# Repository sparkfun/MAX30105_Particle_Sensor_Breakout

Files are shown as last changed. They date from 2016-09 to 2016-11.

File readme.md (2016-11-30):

MAX30105 Particle and Pulse Ox Sensor Breakout
=======

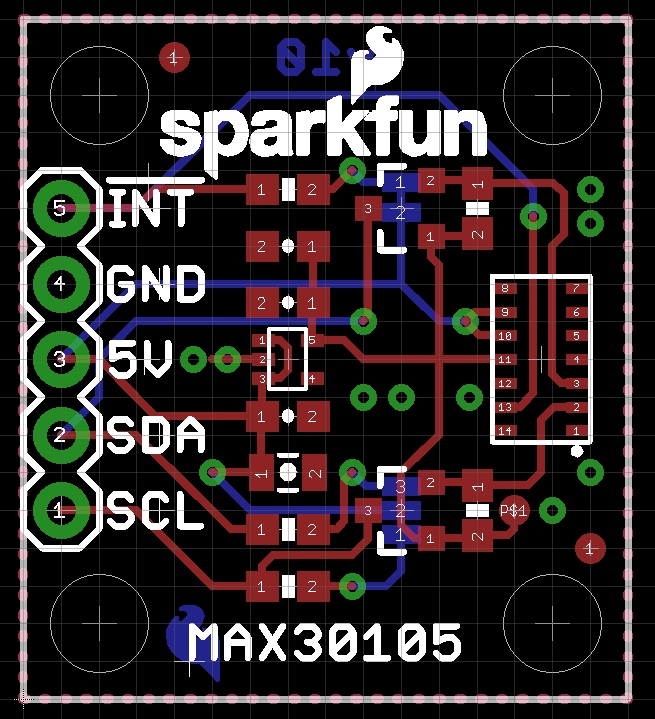
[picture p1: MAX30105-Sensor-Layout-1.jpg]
MAX30105 Breakout Board


A breakout board for the MAX30105 Particle Sensor. This sensor uses three LEDs (Red, Green, IR) to shine different wavelengths of light at any particle in front of the photo detector. Based on the reflection the sensor outputs readings. 

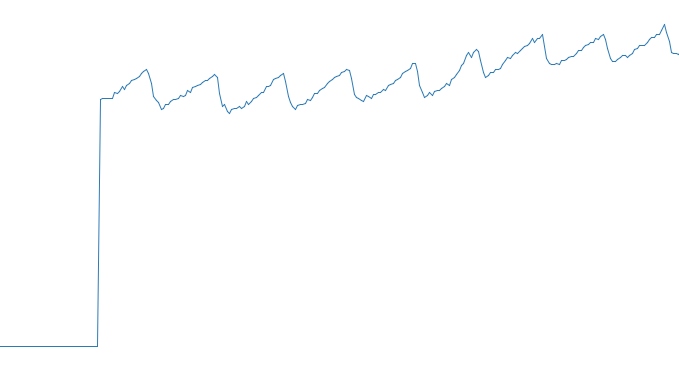
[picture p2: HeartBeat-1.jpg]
Pulse Graph


That's my heart beat!

Sensor is capable of detecting pulses but only limited algorithms are provided. It is up to the user to create the algorithms to detect different particles and/or SPO2 and/or do Pulse Detection.

Board requires 3.3V to operate the IR and Red LEDs. 3.5V is recommended to operate the green LED. It has onboard voltage regulation and BSS138 MOSFETs to convert from larger logic voltages (5V) down to the needed 1.8V.

License Information
-------------------

The hardware is released under [Creative Commons Share-alike 4.0](http://creativecommons.org/licenses/by-sa/4.0/).  
The firmware is released under the [Beerware license](http://en.wikipedia.org/wiki/Beerware).

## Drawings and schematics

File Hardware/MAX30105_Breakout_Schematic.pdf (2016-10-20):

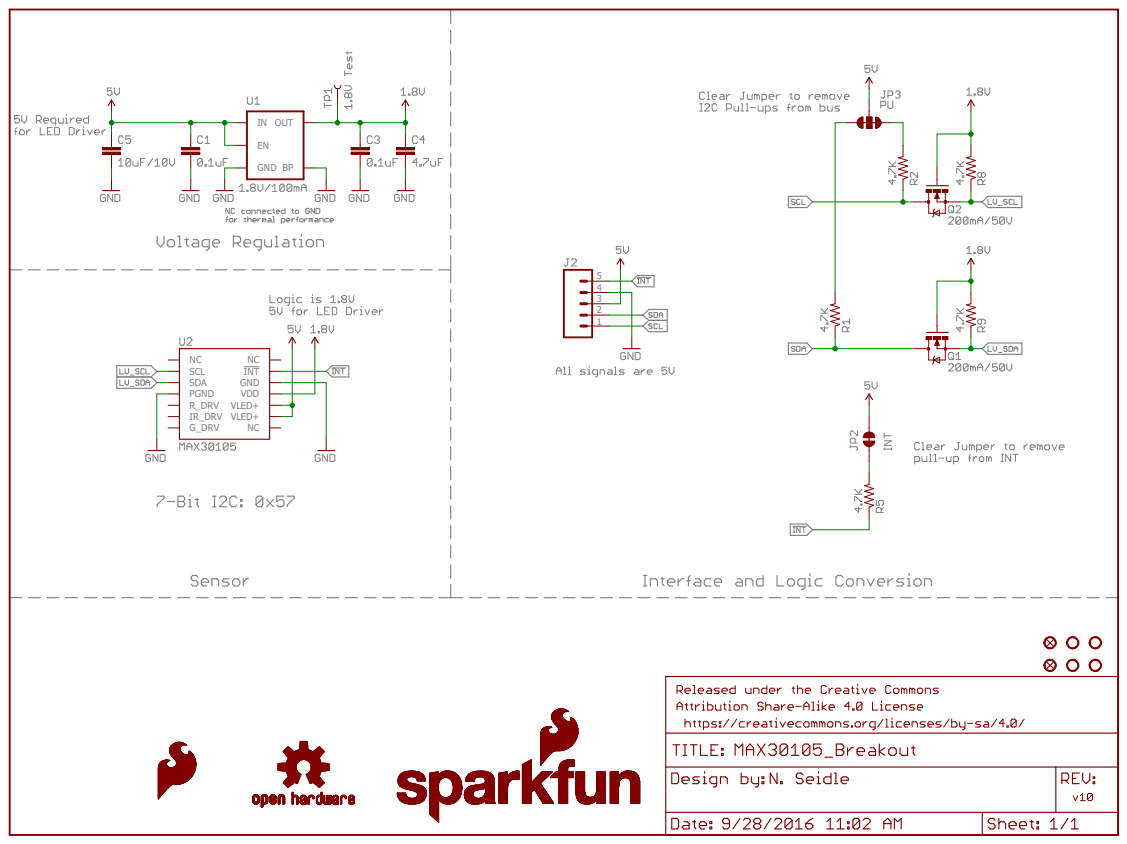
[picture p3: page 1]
SCL; VDD; GND; PGND; G_DRV; IR_DRV; VLED+; INT; R_DRV; SDA; OUT

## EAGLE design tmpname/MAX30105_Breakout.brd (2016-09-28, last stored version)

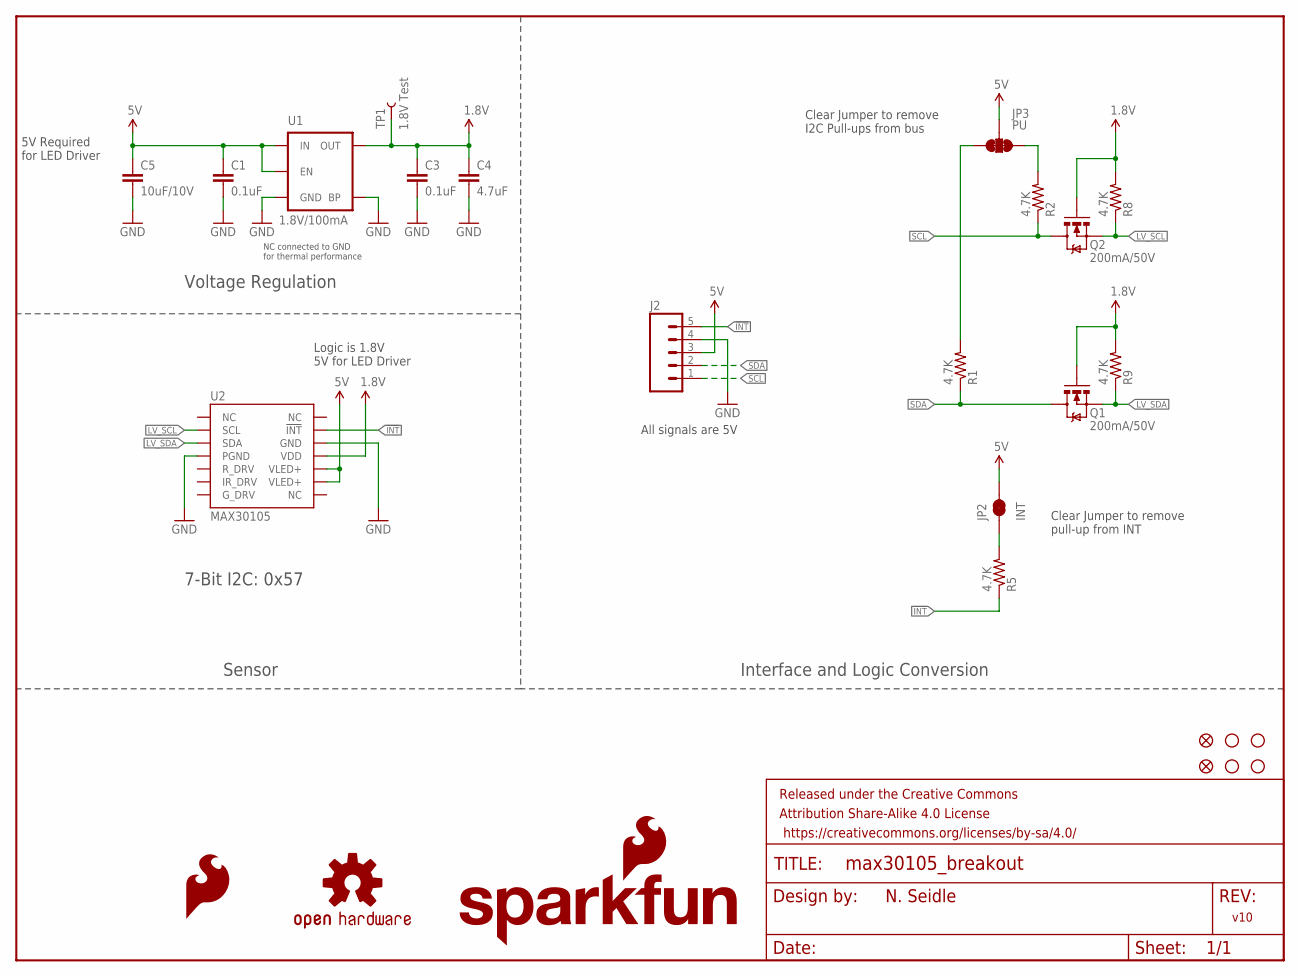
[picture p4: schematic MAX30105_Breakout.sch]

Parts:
C1, C3: 0.1uF; 0603-CAP
C4: 4.7uF; 0603-CAP
C5: 10uF/10V; 0805-CAP
FID1, FID2: FIDUCIAL1X2; FIDUCIAL-1X2
FRAME1: FRAME-LETTER; CREATIVE_COMMONS
J2: M05PTH; 1X05
JP2: INT; PAD-JUMPER-2-NC_BY_TRACE_YES_SILK
JP3: PU; PAD-JUMPER-3-3OF3_NC_BY_TRACE_YES_SILK_FULL_BOX
LOGO1: SFE_LOGO_NAME_FLAME.1_INCH; SFE_LOGO_NAME_FLAME_.1
LOGO2: OSHW-LOGOS; OSHW-LOGO-S
LOGO4: SFE_LOGO_FLAME.1EXP; SFE_LOGO_FLAME_COPPER_EXPOSED_.1
Q1, Q2: 200mA/50V; SOT23-3
R1, R2, R5, R8, R9: 4.7K; 0603-RES
STANDOFF1, STANDOFF2, STANDOFF3, STANDOFF4: STAND-OFF
TP1: 1.8V Test; PAD.03X.04
U1: 1.8V/100mA; SC70
U2: MAX30105; OLGA-14

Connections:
1.8V: C3.1, C4.1, Q1.1 (G), Q2.1 (G), R8.2, R9.2, TP1.P$1, U1.5 (OUT), U2.11 (VDD)
5V: C1.1, C5.1, J2.3, JP2.2, JP3.2, U1.1 (IN), U1.3 (EN), U2.9 (VLED+), U2.10 (VLED+)
!INT: J2.5, R5.1, U2.13 (!INT)
GND: C1.2, C3.2, C4.2, C5.2, J2.4, U1.2 (GND), U1.4 (BP), U2.4 (PGND), U2.12 (GND)
LV_SCL: Q2.2 (S), R8.1, U2.2 (SCL)
LV_SDA: Q1.2 (S), R9.1, U2.3 (SDA)
unnamed: JP2.1, R5.2
unnamed: JP3.1, R2.2
unnamed: JP3.3, R1.2
SCL: J2.1, Q2.3 (D), R2.1
SDA: J2.2, Q1.3 (D), R1.1

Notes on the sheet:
7-Bit I2C: 0x57
v10
N. Seidle
Voltage Regulation
Interface and Logic Conversion
Sensor
5V Required for LED Driver
Clear Jumper to remove I2C Pull-ups from bus
Clear Jumper to remove pull-up from INT
Logic is 1.8V 5V for LED Driver
All signals are 5V
NC connected to GND for thermal performance

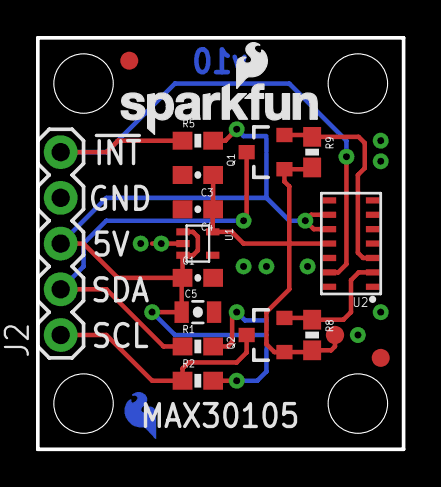
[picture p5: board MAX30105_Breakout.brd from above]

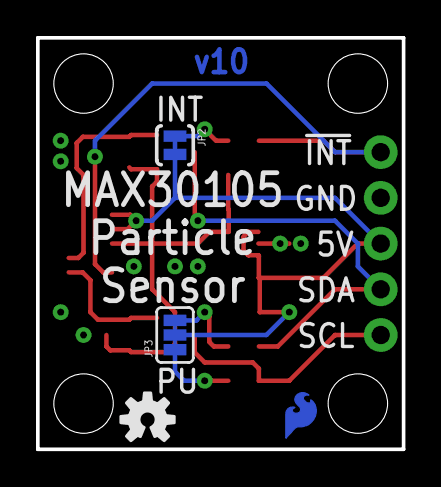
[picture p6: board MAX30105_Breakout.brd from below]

Board: 2 copper layers, 20.3 x 22.9 mm, 27 parts (4 on the bottom side), 11 nets.

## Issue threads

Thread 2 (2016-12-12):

No need to wait after Wire.requestFrom().

Koepel, 2016-12-12:
In the file "MAX30105.cpp" in the function "readRegister8()" there is a delay with a timeout after the Wire.requestFrom(). The Wire.requestFrom() waits until the i2c session has completely finished. After that the data is in a buffer inside the Wire library. The Wire.available() returns the number of bytes that are waiting in that buffer. There is no need to wait for retrieving data from that buffer, since the i2c session has already finished.

I did not check the datasheet. Some sensors do not acknowledge their i2c address when they are busy. In that case the Wire.requestFrom() should be repeated.
The Wire.available() could be used once, or the return value of Wire.requestFrom() could be used to check if no data was received and a fail (zero) should be returned.

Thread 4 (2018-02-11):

Example 8 SPO2 Code Error

bhernandez0, 2018-02-11:
When I try to upload the code to a Arduino Pro Mini I am receiving this error:

Example8_SPO2:96: error: cannot convert 'uint16_t* {aka unsigned int*}' to 'uint32_t* {aka long unsigned int*}' for argument '1' to 'void maxim_heart_rate_and_oxygen_saturation(uint32_t*, int32_t, uint32_t*, int32_t*, int8_t*, int32_t*, int8_t*)'

   maxim_heart_rate_and_oxygen_saturation(irBuffer, bufferLength, redBuffer, &spo2, &validSPO2, &heartRate, &validHeartRate);

Is there a fix for this?

nseidle, 2018-02-15:
Ya, it's this [line](https://github.com/sparkfun/SparkFun_MAX3010x_Sensor_Library/blob/master/src/spo2_algorithm.cpp#L63) (ok a couple of these lines in h and ino). Needs to be changed to

    #if defined(__AVR_ATmega328P__) || defined(__AVR_ATmega168__)

nseidle, 2018-02-15:
Should be fixed in v1.0.3

bhernandez0, 2018-02-16:
Thank You!!! Works great now

nseidle, 2018-02-16:
Excellent!

zlocimir, 2020-02-17:
Any idea on how to get it working on NodeMCU?
Every other example is working just fine

This is what serial monitor returns:
 ets Jan  8 2013,rst cause:4, boot mode:(3,6)

wdt reset
load 0x4010f000, len 1392, room 16
tail 0
chksum 0xd0
csum 0xd0
v3d128e5c
~ld

Closed 2018-02-15.

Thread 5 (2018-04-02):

Example4 "byte sampleRate = 100; "

pengu-lee, 2018-04-02:
Hi, i found that sampleRate could be more than 255, but the data type of sampleRate is byte, maybe short or int  is more proper.

nseidle, 2018-04-03:
This issue was moved to sparkfun/SparkFun_MAX3010x_Sensor_Library#14

Closed 2018-04-03.

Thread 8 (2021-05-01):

GY-MAX30100 Example8_SPO2 issue

simtcrom, 2021-05-01:
Hello,

My sensor model is GY-MAX30100 picture attached.
I am trying Example8_SPO2, and in the serial monitor I get below,

 _ets Jan  8 2013,rst cause:4, boot mode:(3,6)

wdt reset
load 0x4010f000, len 3584, room 16
tail 0
chksum 0xb0
csum 0xb0
v2843a5ac
~ld_

I know the sensor works, Example1_Basic_Readings, Example4_HeartBeat_Plotter, Example5_HeartRate worked.
Any idea how to fix it ?

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

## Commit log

2016-09-13 Adding hardware files.
    [MAX30105_Breakout.brd, MAX30105_Breakout.sch]
2016-09-13 Fixes from QC check.
    [MAX30105_Breakout.brd, MAX30105_Breakout.sch]
2016-09-13 Mostly cosmetic changes from review.
    Added text to schematic. Changed drill hits to 0.015. Reduced paste pads
    to 75% (roughly) on IC. Created library with only sensor FP.
    [MAX30105_Breakout.brd, MAX30105_Breakout.sch]
2016-09-15 Fixed typo in schematic
    [MAX30105_Breakout.sch]
2016-09-28 Update version to v10
    [MAX30105_Breakout.brd, MAX30105_Breakout.sch]
2016-10-20 Adding schematic and images.
2016-11-30 Fixing directory structure
    [MAX30105_Breakout.brd, MAX30105_Breakout.sch]
2016-11-30 Squashed 'Libraries/Arduino/' content from commit 556c675
    git-subtree-dir: Libraries/Arduino
    git-subtree-split: 556c675a13e3338c9387609c89f57d7b1440020d
2017-08-17 Correct capitalization of Arduino.h
    The filename was incorrectly specified as arduino.h, which causes compilation to fail on filename case sensitive operating systems such as Linux.

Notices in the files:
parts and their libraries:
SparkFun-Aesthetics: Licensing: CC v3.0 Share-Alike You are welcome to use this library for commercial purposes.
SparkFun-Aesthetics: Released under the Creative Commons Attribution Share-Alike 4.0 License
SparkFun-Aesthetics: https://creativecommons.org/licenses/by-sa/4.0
